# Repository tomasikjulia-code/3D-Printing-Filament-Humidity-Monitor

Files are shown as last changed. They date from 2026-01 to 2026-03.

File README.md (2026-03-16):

# 3D Printing Filament Humidity Monitor

Board designed to monitor storage conditions for 3D printing filaments. Using the **DHT22** sensor, this board ensures your hygroscopic materials stay within the optimal humidity range to prevent printing defects.

---

## Why It Matters
Moisture is the enemy of high-quality 3D prints. This project helps you:
* **Prevent Stringing & Bubbles:** Identify when filament needs drying.
* **Monitor Dryboxes:** Real-time tracking of internal humidity in sealed containers.
* **Optimize Print Quality:** Ensure consistent extrusion by maintaining dry material.

---

## Features
* **Sensor:** DHT22 High-accuracy capacitive humidity and temperature sensor.
* **Microcontroller:** STM32F103C8Tx.
* **Local Display:** Support for I2C OLED (SH1106) to check status at a glance.
* **Power:** Powered by Li-Po accumulator with charger TP4056 USB-C

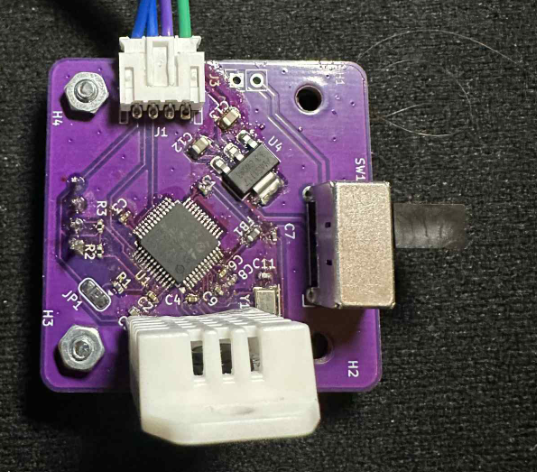
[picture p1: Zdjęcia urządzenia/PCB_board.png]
Filament Monitor Board


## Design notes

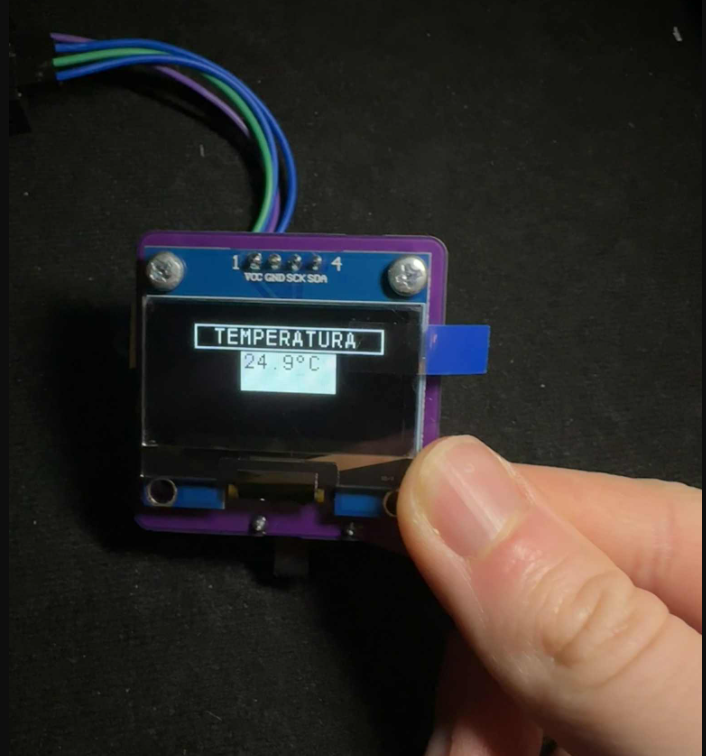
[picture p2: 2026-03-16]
Zdjęcia urządzenia/display_photo.png

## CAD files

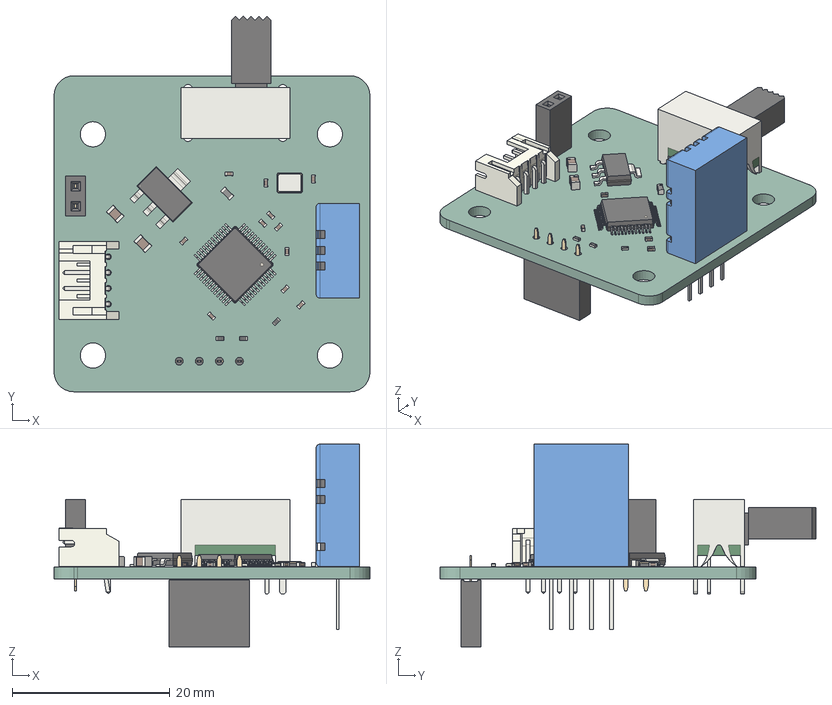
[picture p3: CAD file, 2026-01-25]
KiCAD/humidity_sensor.step
40.0 x 47.5 x 25.7 mm
Crystal_SMD_3225-4Pin_3.2x2.5mm
L_0603_1608Metric
C_0402_1005Metric x 11
Aosong_DHT11_5.5x12.0_P2.54mm
C_0805_2012Metric x 2
R_0402_1005Metric x 3
SW_E-Switch_EG1224_SPDT_Angled
SOT-223
JST_PH_S4B-PH-K_1x04_P2.00mm_Horizontal
PinSocket_1x02_P2.54mm_Vertical
LQFP-48_7x7mm_P0.5mm
PinSocket_1x04_P2.54mm_Vertical
humidity_sensor_PCB

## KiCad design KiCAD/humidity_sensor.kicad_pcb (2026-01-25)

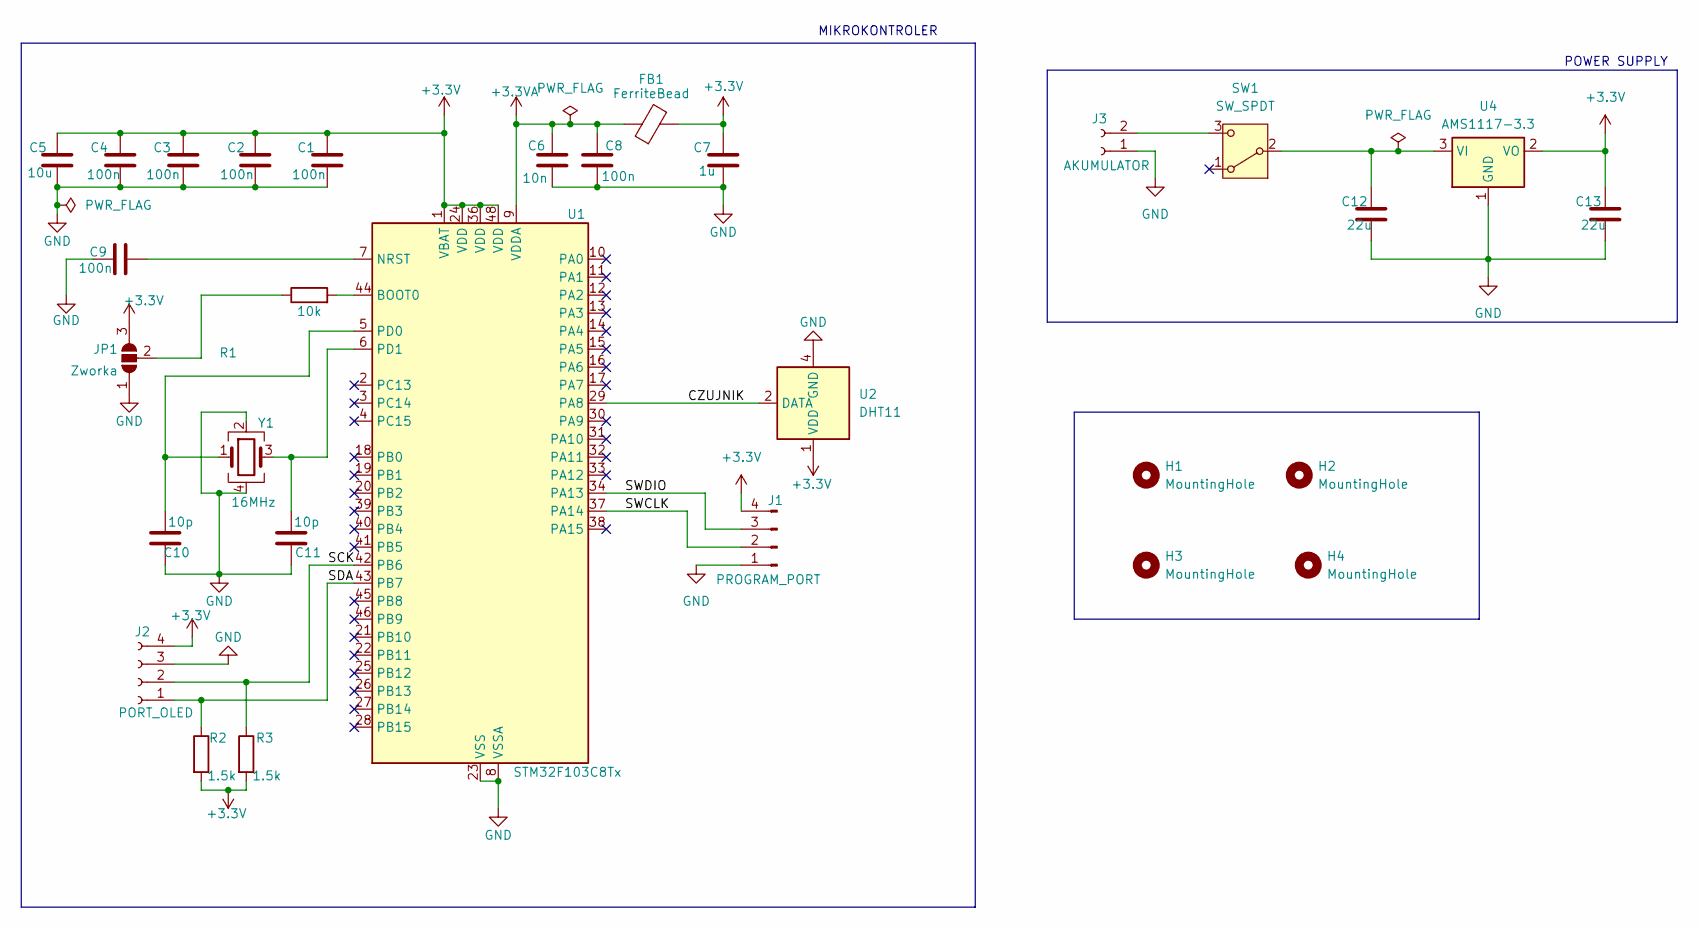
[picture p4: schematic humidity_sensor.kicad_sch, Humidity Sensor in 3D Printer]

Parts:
C1, C2, C3, C4, C8, C9: 100n; C_0402_1005Metric
C5: 10u; C_0402_1005Metric
C6: 10n; C_0402_1005Metric
C7: 1u; C_0402_1005Metric
C10, C11: 10p; C_0402_1005Metric
C12, C13: 22u; C_0805_2012Metric
FB1: FerriteBead; L_0603_1608Metric
H1, H2, H3, H4: MountingHole; MountingHole_3.2mm_M3
J1: PROGRAM_PORT; JST_PH_S4B-PH-K_1x04_P2.00mm_Horizontal
J2: PORT_OLED; PinSocket_1x04_P2.54mm_Vertical
J3: AKUMULATOR; PinSocket_1x02_P2.54mm_Vertical
JP1: Zworka; SolderJumper-3_P1.3mm_Open_RoundedPad1.0x1.5mm
R1: 10k; R_0402_1005Metric
R2, R3: 1.5k; R_0402_1005Metric
SW1: SW_SPDT; SW_E-Switch_EG1224_SPDT_Angled
U1: STM32F103C8Tx; LQFP-48_7x7mm_P0.5mm
U2: DHT11; Aosong_DHT11_5.5x12.0_P2.54mm
U4: AMS1117-3.3; SOT-223-3_TabPin2
Y1: 16MHz; Crystal_SMD_3225-4Pin_3.2x2.5mm

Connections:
+3.3V: C1.1, C2.1, C3.1, C4.1, C5.1, C7.1, C13.1, FB1.2, J1.4, J2.4, JP1.3 (B), R2.2, R3.2, U1.1 (VBAT), U1.24 (VDD), U1.36 (VDD), U1.48 (VDD), U2.1 (VDD), U4.2 (VO)
+3.3VA: C6.1, C8.1, FB1.1, U1.9 (VDDA)
/CZUJNIK: U1.29 (PA8), U2.2 (DATA)
/SCK: J2.2, R3.1, U1.42 (PB6)
/SDA: J2.1, R2.1, U1.43 (PB7)
/SWCLK: J1.2, U1.37 (PA14)
/SWDIO: J1.3, U1.34 (PA13)
GND: C1.2, C2.2, C3.2, C4.2, C5.2, C6.2, C7.2, C8.2, C9.1, C10.1, C11.1, C12.2, C13.2, J1.1, J2.3, J3.1, JP1.1 (A), U1.8 (VSSA), U1.23 (VSS), U1.35 (VSS), U1.47 (VSS), U2.4 (GND), U4.1 (GND), Y1.2, Y1.4
unnamed: J3.2, SW1.3 (C)
unnamed: JP1.2 (C), R1.1
unnamed: C12.1, SW1.2 (B), U4.3 (VI)
unnamed: R1.2, U1.44 (BOOT0)
unnamed: C9.2, U1.7 (NRST)
unnamed: C10.2, U1.5 (PD0), Y1.1
unnamed: C11.2, U1.6 (PD1), Y1.3

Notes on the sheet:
POWER SUPPLY
MIKROKONTROLER

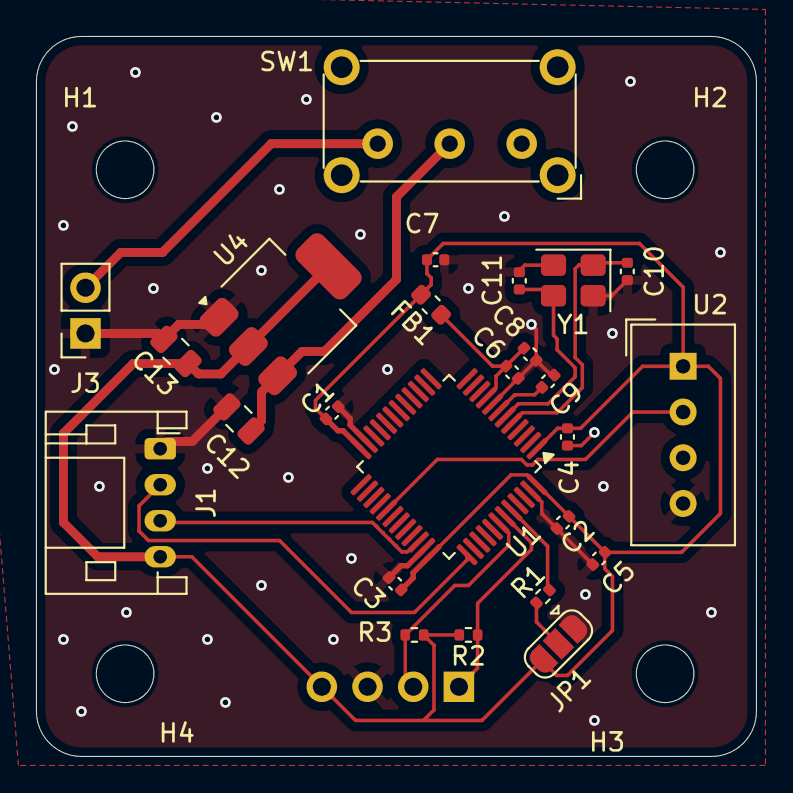
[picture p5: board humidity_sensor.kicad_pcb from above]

Board: 2 copper layers, 40.0 x 40.0 mm, 30 parts (1 on the bottom side), 15 nets.

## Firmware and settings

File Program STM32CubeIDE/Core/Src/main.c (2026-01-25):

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
/* Includes ------------------------------------------------------------------*/
#include "main.h"
#include "i2c.h"
#include "tim.h"
#include "gpio.h"

/* USER CODE BEGIN Includes */
#include"fonts.h"
#include"SH1106.h"
#include"bitmap.h"
/* USER CODE END Includes */


void SystemClock_Config(void);
/* USER CODE BEGIN 0 */


/*******************************DHT22 FUNCTIONS *****************************************/
uint8_t Rh_byte1, Rh_byte2, Tmp_byte1, Tmp_byte2;
uint16_t Sum, Rh, Tmp;
float Temperature = 0;
float Humidity = 0;
uint8_t Presence = 0;
char str[20];

void display_view(){
	SH1106_Fill(SH1106_COLOR_BLACK);
	SH1106_DrawRectangle(20, 5, 100, 12,SH1106_COLOR_WHITE);
	SH1106_GotoXY(30, 7);
	SH1106_Puts("TEMPERATURA", &Font_7x10, SH1106_COLOR_WHITE);
	SH1106_DrawFilledRectangle(45,19, 50, 20, 1);
	SH1106_GotoXY(46, 20);
	sprintf(str, "%.1f%cC", Temperature, 127);

	SH1106_Puts(str, &Font_7x10, SH1106_COLOR_BLACK);
	SH1106_UpdateScreen();
}
void Set_Pin_Output(GPIO_TypeDef *GPIOx, uint16_t GPIO_Pin){
	GPIO_InitTypeDef GPIO_InitStruct = {0};
	GPIO_InitStruct.Pin = GPIO_Pin;
	GPIO_InitStruct.Mode = GPIO_MODE_OUTPUT_PP;
	GPIO_InitStruct.Speed = GPIO_SPEED_FREQ_LOW;
	HAL_GPIO_Init(GPIOx, &GPIO_InitStruct);
}
void Set_Pin_Input(GPIO_TypeDef *GPIOx, uint16_t GPIO_Pin){
	GPIO_InitTypeDef GPIO_InitStruct = {0};
	GPIO_InitStruct.Pin = GPIO_Pin;
	GPIO_InitStruct.Mode = GPIO_MODE_INPUT;
	GPIO_InitStruct.Pull = GPIO_PULLUP;
	HAL_GPIO_Init(GPIOx, &GPIO_InitStruct);
}
void delay(uint16_t time){
	__HAL_TIM_SET_COUNTER(&htim1, 0);
	while(__HAL_TIM_GET_COUNTER(&htim1)< time);
}

void DHT22_Start(){
	Set_Pin_Output(SENSOR_GPIO_Port, SENSOR_Pin);
	HAL_GPIO_WritePin(SENSOR_GPIO_Port, SENSOR_Pin, 0);
	HAL_Delay(18);

	HAL_GPIO_WritePin(SENSOR_GPIO_Port, SENSOR_Pin, 1);
	delay(40);
	Set_Pin_Input(SENSOR_GPIO_Port, SENSOR_Pin);
}
uint8_t DHT22_Check_Response()
{
	Set_Pin_Input(SENSOR_GPIO_Port, SENSOR_Pin);
	uint8_t Response = 0;
	uint16_t timeout = 0;
	delay(40);
	if (!(HAL_GPIO_ReadPin (SENSOR_GPIO_Port, SENSOR_Pin)))
	{
		delay (80);

		if ((HAL_GPIO_ReadPin (SENSOR_GPIO_Port, SENSOR_Pin))) Response = 1;
		else Response = -1;
	}

	timeout = 0;
	    while ((HAL_GPIO_ReadPin(SENSOR_GPIO_Port, SENSOR_Pin)) && timeout < 500) {
	        timeout++;
	        delay(1);
	    }

	    if (timeout >= 500) return 0;
	    return Response;
}
uint8_t DHT22_Read()
{
	uint8_t i,j;
	for (j=0;j<8;j++)
	{
		while (!(HAL_GPIO_ReadPin (SENSOR_GPIO_Port, SENSOR_Pin)));
		delay (40);   // wait for 40 us

		if (!(HAL_GPIO_ReadPin (SENSOR_GPIO_Port, SENSOR_Pin)))
		{
			i&= ~(1<<(7-j));   // write 0
		}
		else i|= (1<<(7-j));  // if the pin is high, write 1
		while ((HAL_GPIO_ReadPin (SENSOR_GPIO_Port, SENSOR_Pin)));  // wait for the pin to go low
	}

	return i;
}
/* USER CODE END 0 */

/**
  * @brief  The application entry point.
  * @retval int
  */
int main(void)
{

  /* MCU Configuration--------------------------------------------------------*/

  /* Reset of all peripherals, Initializes the Flash interface and the Systick. */
  HAL_Init();

  /* Configure the system clock */
  SystemClock_Config();

  /* Initialize all configured peripherals */
  MX_GPIO_Init();
  MX_I2C1_Init();
  MX_TIM1_Init();
  /* USER CODE BEGIN 2 */
  SH1106_Init();
  SH1106_UpdateScreen();
  HAL_TIM_Base_Start(&htim1);
  /* USER CODE END 2 */

  /* Infinite loop */
  /* USER CODE BEGIN WHILE */

  while (1)
  {
	  DHT22_Start();
	  Presence = DHT22_Check_Response();
	  Rh_byte1 = DHT22_Read ();
	  Rh_byte2 = DHT22_Read ();
	  Tmp_byte1 = DHT22_Read ();
	  Tmp_byte2 = DHT22_Read ();
	  Sum = DHT22_Read();
      Tmp = ((Tmp_byte1<<8)|Tmp_byte2);
      Rh = ((Rh_byte1<<8)|Rh_byte2);

      if (Tmp_byte1 & 0x80) {
          Temperature = (float)((Tmp & 0x7FFF) / 10.0) * -1.0;
      } else {
          Temperature = (float)(Tmp / 10.0);
      }
      Humidity = (float) (Rh/10.0);
      display_view();
      HAL_Delay(2000);

    /* USER CODE END WHILE */

    /* USER CODE BEGIN 3 */
  }
  /* USER CODE END 3 */
}

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


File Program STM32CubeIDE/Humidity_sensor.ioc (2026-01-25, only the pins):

Mcu.UserName=STM32F103C8Tx
PA13.Signal=SYS_JTMS-SWDIO
PA14.Signal=SYS_JTCK-SWCLK
PA8.GPIO_Label=SENSOR
PA8.Signal=GPIO_Output
PB6.Signal=I2C1_SCL
PB7.Signal=I2C1_SDA
PD0-OSC_IN.Signal=RCC_OSC_IN
PD1-OSC_OUT.Signal=RCC_OSC_OUT

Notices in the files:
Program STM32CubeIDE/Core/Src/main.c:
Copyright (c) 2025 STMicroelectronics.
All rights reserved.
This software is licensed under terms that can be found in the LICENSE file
